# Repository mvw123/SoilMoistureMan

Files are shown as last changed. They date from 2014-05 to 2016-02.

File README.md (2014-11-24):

Soil Moisture Man [WIP]
===============

WARNING: THIS PROJECT WILL CAUSE ELECTROLYSIS AND SO THE PLATING ON THE LEGS WILL DEGRADE OVER TIME. SOME CONTAMINATION OF THE SOIL WILL OCCUR. DO NOT USE ON EDIBLE PLANTS. 

The Soil moisture man CAD files are drawn using Eagle CAD free edition. 
Simulation files are included. These use Simetrix (windows only) http://www.simetrix.co.uk/site/index.html

The Soil Moisture Man is an educational "open source hardware" project which flashes warning LEDs when your plants soil becomes dry. 
This stops you under-watering and killing your plants. 
* The device uses standard electronic circuits to measure the resistance of the soil. 
* Transistors and variable resistor test the soil moisture level and switch the circuit on when required
* An Astable multivibrator is used to flash the LEDs at a certain frequency and duty cycle. 
* This is NOT a commercial product and is not suitable for commercial sale. It is to be used solely for educational use. We (i) do not warrant its use in any way shape or form. 

To use the soil moisture man, you need to calibrate the device to flash its LEDs when your soil becomes dry to the point where it will need watering. 
You do this by :- 
* Select a plant whose soil has just reached the point where it needs watering, but where the soil is not dry or parched.
* Insert the gold coloured legs into the soil next to a plant, up to the point where the gold flashing on the legs stops. Inserting the device further could damage the circuitry.
* IMPORTANT: Press the soil firmly against the legs, so that it makes good contact. Failing to do this will cause the LEDs to flash in error.
* Turn VR1 until the LEDs just start to flash consistently. 
* Note that different types of soil have different resistances. If you have a multimeter, its interesting to do take some measurements in different soil types. This project is setup for house plants which usually use a fine soil which has a lower resistance than the soil you would normally find in your back garden. 

CAD C [WIP]
===========

CAD C is being updated due to some minor issues on CAD B which have been raised in github.
Battery lifetime is being tested. 

CAD B [TESTED - Some issues present] 
=====

Changed the circuit around from CAD A. 
The Astable multivibrator is now turned on by the soil moisture sensor transistor. 
This saves some small amounts of power and thus increases the battery life.
BOM parts updated and new VR1 chosen

CAD A [FAULTY] 
=====

Initial schematic release.
Ignore this version, it has been superseded by CAD B
Released to OSH park with a bug. 
The ground track was missing on the VR1 trimmer
The CAM file output did not work correctly due to the solder mask resist keep out area size. it needed pulling back from the edge of the PCB.
Final component selection was not completed and has now changed on CAD B. 
The circuit design changed on CAD B.

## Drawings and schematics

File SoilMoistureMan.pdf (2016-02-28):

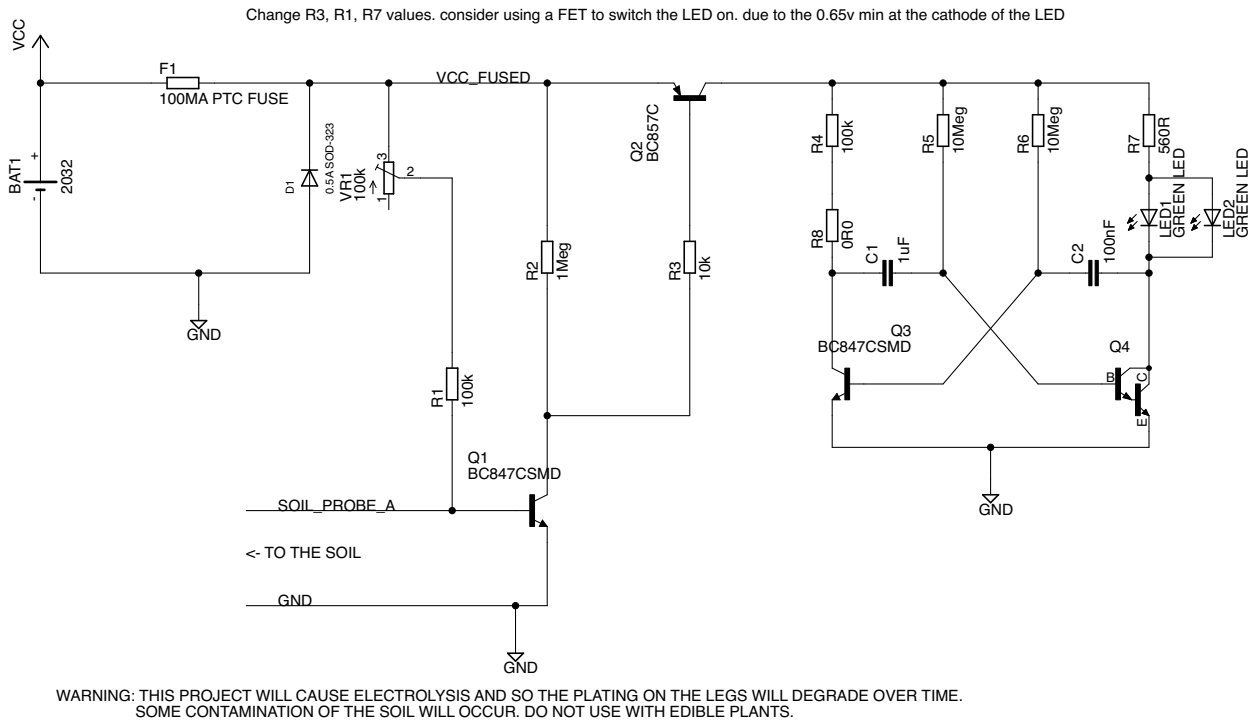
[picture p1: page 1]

Change R3, R1, R7 values. consider using a FET to switch the LED on. due to the 0.65v min at the cathode of the LED

GREEN LED

SOME CONTAMINATION OF THE SOIL WILL OCCUR. DO NOT USE WITH EDIBLE PLANTS. WARNING: THIS PROJECT WILL CAUSE ELECTROLYSIS AND SO THE PLATING ON THE LEGS WILL DEGRADE OVER TIME.

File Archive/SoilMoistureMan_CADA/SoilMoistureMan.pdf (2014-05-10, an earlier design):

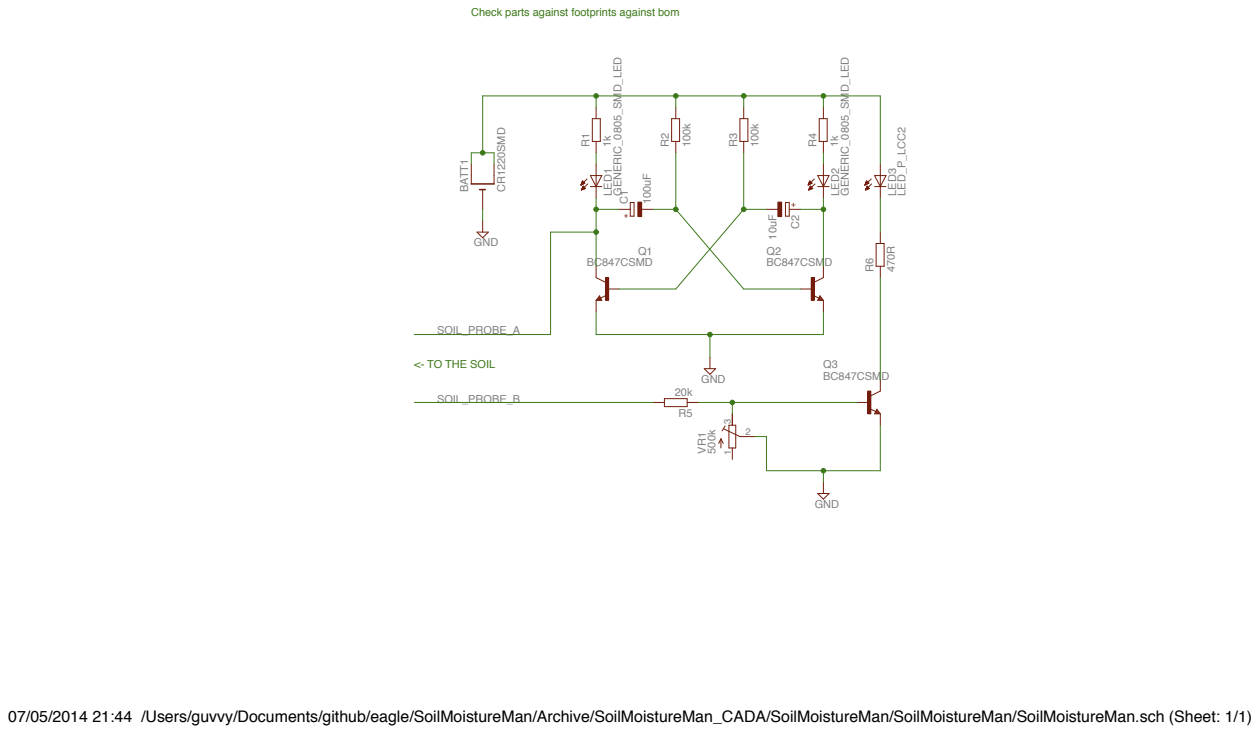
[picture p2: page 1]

Check parts against footprints against bom

07/05/2014 21:44 /Users/guvvy/Documents/github/eagle/SoilMoistureMan/Archive/SoilMoistureMan_CADA/SoilMoistureMan/SoilMoistureMan/SoilMoistureMan.sch (Sheet: 1/1)

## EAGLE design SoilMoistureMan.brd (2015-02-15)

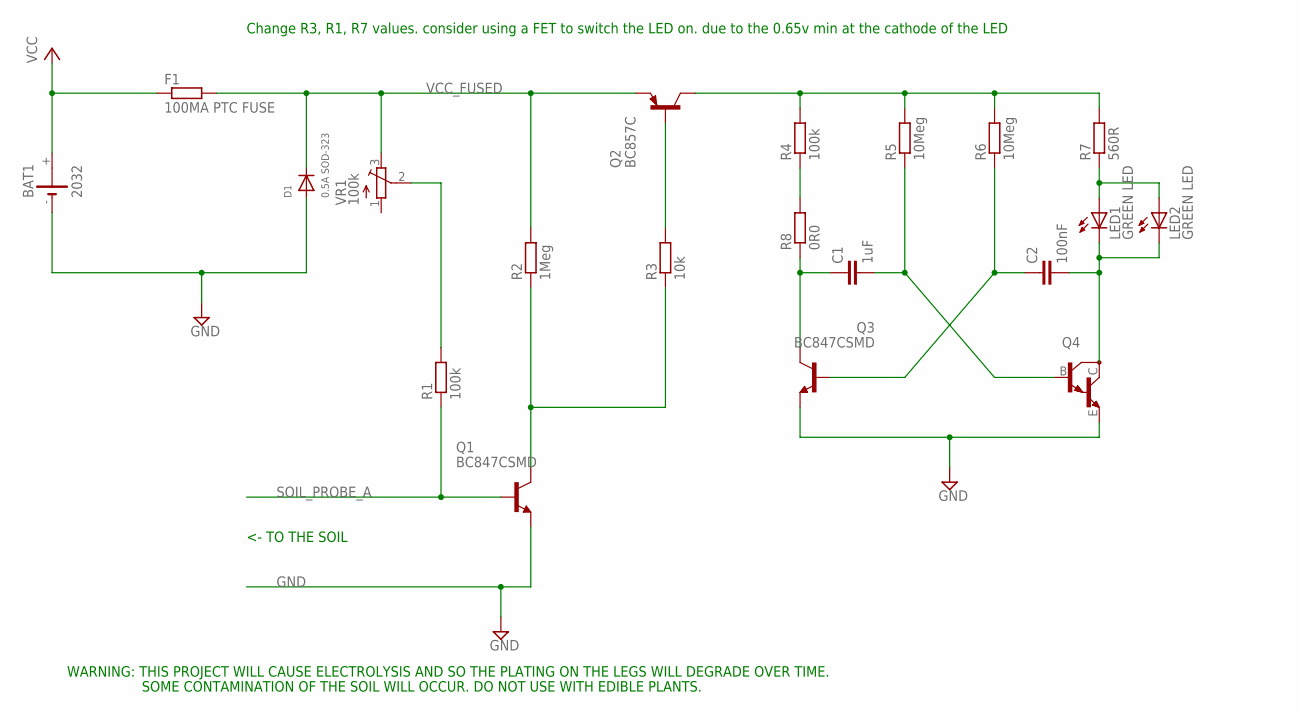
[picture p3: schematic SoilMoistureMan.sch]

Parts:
BAT1: 2032; KZH20SMD; MPN SMTU 2032-LF
C1: 1uF; C0603; MPN C1608X5R1C105K080AA
C2: 100nF; C0603; MPN MC0603B104K160CT
D1: 0.5A SOD-323; SOD-323F; MPN PMEG3010EJ,115
F1: 100MA PTC FUSE; R0805; MPN MF-PSMF010X-2
LED1, LED2: GREEN LED; P-LCC-2; MPN LGT67K-H2K1-24-Z
Q1, Q3: BC847CSMD; SOT23; MPN BC847C-7-F
Q2: BC857C; SOT23-BEC; MPN BC857C-7-F
Q4: MMBTA13LT1; SOT23-BEC; MPN BCV27
R1, R4: 100k; R0603; MPN CRGH0603J100K
R2: 1Meg; R0603; MPN CRGH0603J1M0
R3: 10k; R0603; MPN CR0603-JW-103GLF
R5, R6: 10Meg; R0603; MPN MC0063W0603110M0
R7: 560R; R0603; MPN CRGH0603J560R
R8: 0R0; R0603; MPN MC0603SAF0000T5E
VR1: 100k; TC33X; MPN TS53YJ104MR10

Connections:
GND: BAT1.-, D1.A, Q1.2 (E), Q3.2 (E), Q4.E
unnamed: Q2.C, R4.2, R5.2, R6.2, R7.2
unnamed: R4.1, R8.2
unnamed: Q2.B, R3.2
unnamed: LED1.A, LED2.A, R7.1
unnamed: C1.1, Q3.3 (C), R8.1
unnamed: R1.2, VR1.2 (S)
unnamed: C2.1, Q3.1 (B), R6.1
unnamed: C2.2, LED1.C, LED2.C, Q4.C
unnamed: C1.2, Q4.B, R5.1
unnamed: Q1.3 (C), R2.1, R3.1
SOIL_PROBE_A: Q1.1 (B), R1.1
VCC: BAT1.+, F1.1
VCC_FUSED: D1.C, F1.2, Q2.E, R2.2, VR1.3 (E)

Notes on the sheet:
<- TO THE SOIL
SOME CONTAMINATION OF THE SOIL WILL OCCUR. DO NOT USE WITH EDIBLE PLANTS.
WARNING: THIS PROJECT WILL CAUSE ELECTROLYSIS AND SO THE PLATING ON THE LEGS WILL DEGRADE OVER TIME.
Change R3, R1, R7 values. consider using a FET to switch the LED on. due to the 0.65v min at the cathode of the LED

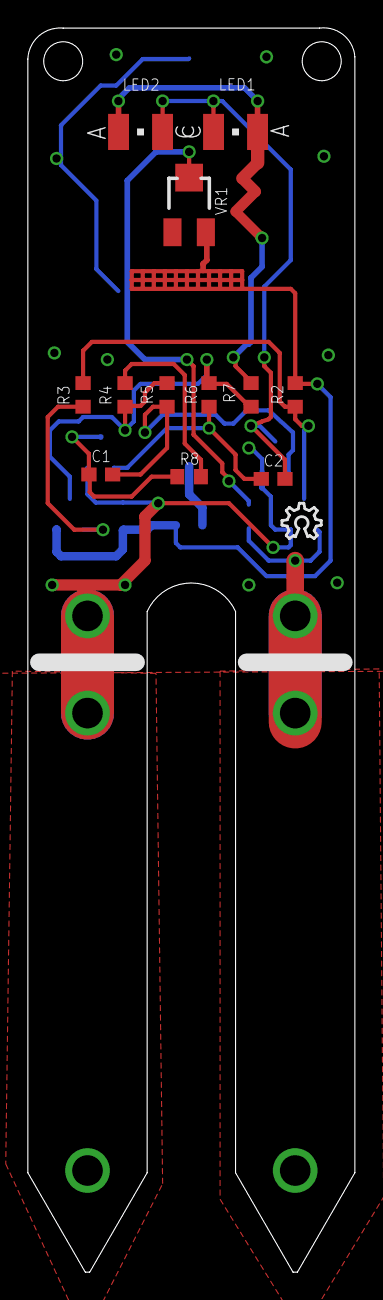
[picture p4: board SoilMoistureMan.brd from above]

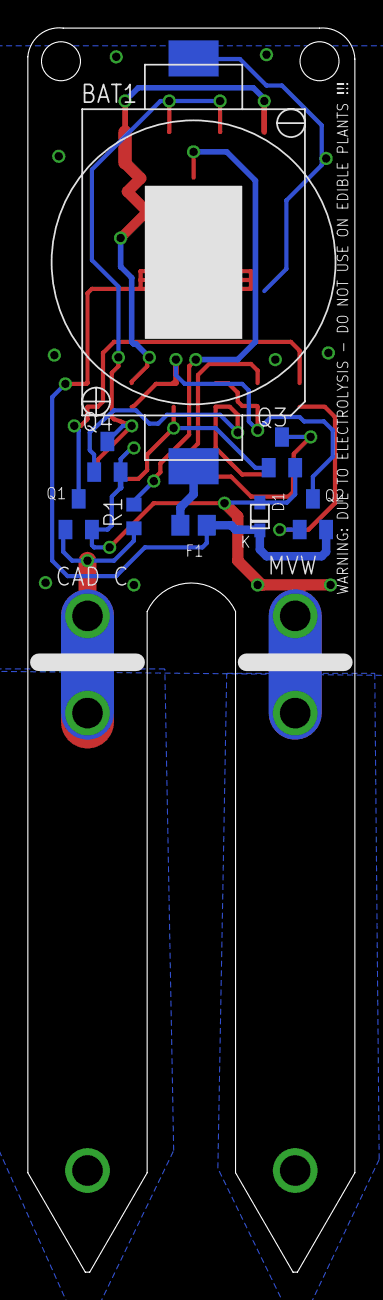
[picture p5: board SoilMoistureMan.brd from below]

Board: 2 copper layers, 23.5 x 89.4 mm, 21 parts (8 on the bottom side), 14 nets.

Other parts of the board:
U$1: OSHW_8X100_NOTEXT

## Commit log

2014-05-02 First commit for WIP CAD B of soil moisture man
    First commit for WIP CAD B of soil moisture man
    CAD A is archived in the zip file. But CAD A won’t work due to missing
    a ground connection on the VR1 trimmer
    [SoilMoistureMan.brd, SoilMoistureMan.sch]
2014-05-02 adding extra components
    started adding extra components to ensure circuitry works
2014-05-05 schematic and Routing changes
    schematic and Routing changes still WIP
    [SoilMoistureMan.brd, SoilMoistureMan.sch]
2014-05-07 Layout changes and Bat 2 changed to bat 1
    [SoilMoistureMan.brd, SoilMoistureMan.sch]
2014-10-02 CAD B Commit
    CAD B Commit - used to produce CAD B boards
    [SoilMoistureMan.brd, SoilMoistureMan.sch]
2014-10-12 First CAD C commit
    Updated one resistor value from 1MOhm to 100k. added warning text about
    electrolysis to pcb and another to the schematic
    [SoilMoistureMan.brd, SoilMoistureMan.sch]
2014-11-24 Committing latest updates on CAD C
    Committing latest updates on CAD C
    [SoilMoistureMan.brd, SoilMoistureMan.sch]
2014-12-21 committing latest updates
    committing latest updates
    [SoilMoistureMan.brd, SoilMoistureMan.sch]
2015-02-15 latest commit
    [SoilMoistureMan.brd]
2016-02-28 Added pdf of schematic
    Added pdf of schematic
